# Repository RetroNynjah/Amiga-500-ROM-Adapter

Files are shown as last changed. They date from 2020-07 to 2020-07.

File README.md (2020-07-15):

# Amiga 500 ROM Adapter
Adapter board that allows use of regular EPROMS on Amiga 500 Rev 5 boards
A500 boards with revision 6 and higher don't have these problems and don't need this adapter.

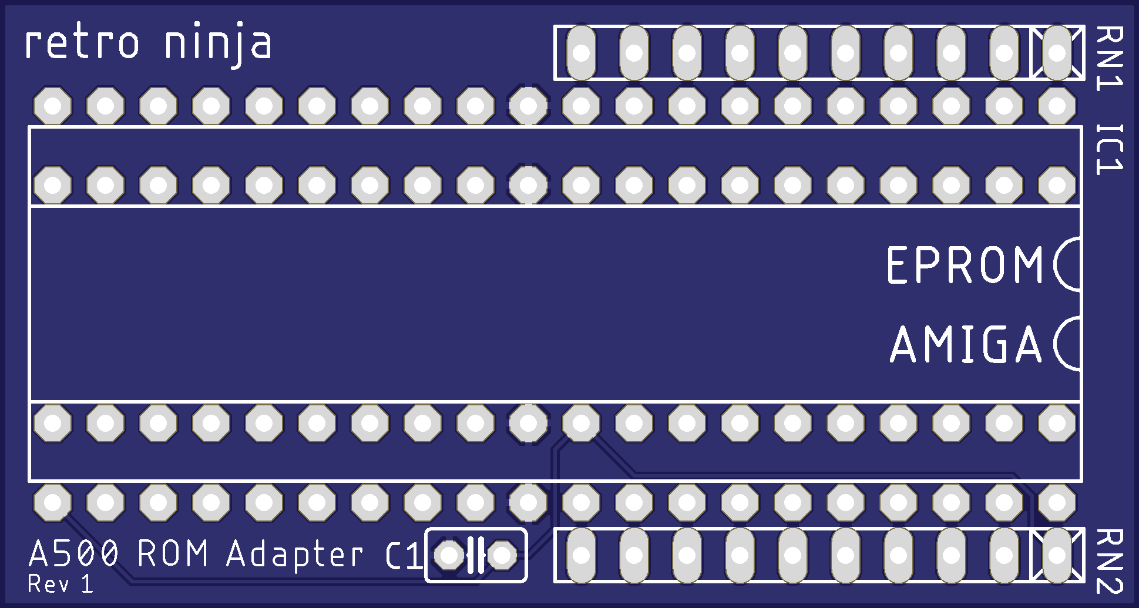
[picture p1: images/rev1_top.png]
PCB top
<br/>

To be able to use regular 27C400 or 27C800 EPROMS on Amiga 500 Rev 5 boards, you will need to lift out pin 31 on the chip, connecting it to VCC and instead connect pin 31 in the socket to pin 1 on the chip.
If that wasn't enough there are compatibility problems between some EPROMS and some machines/CPUs which requires pull-up resistors on the address pins.
This simple adapter board solves both problems. It re-routes the EPROM pins and has place for two optional resistor nets.

<br/>
*Diag ROM installed on a Rev 5 board*

## BOM
 |Component|Pcs |Name|Comment|
 |:--------|---:|:---|:------|
 | 100nF  ceramic capacitor| 1 | C1 | |
 | 4.7k resistor array | 1 | RN1, RN2 | 9 resistor arry (10SIP). 10k is probably OK as well| 
 | DIL-40 socket | 1 || EPROM socket for top side| 
 | 20-pin header | 2 || Round machined pin headers for bottom side (mates with motherboard) | 

Retro Ninja

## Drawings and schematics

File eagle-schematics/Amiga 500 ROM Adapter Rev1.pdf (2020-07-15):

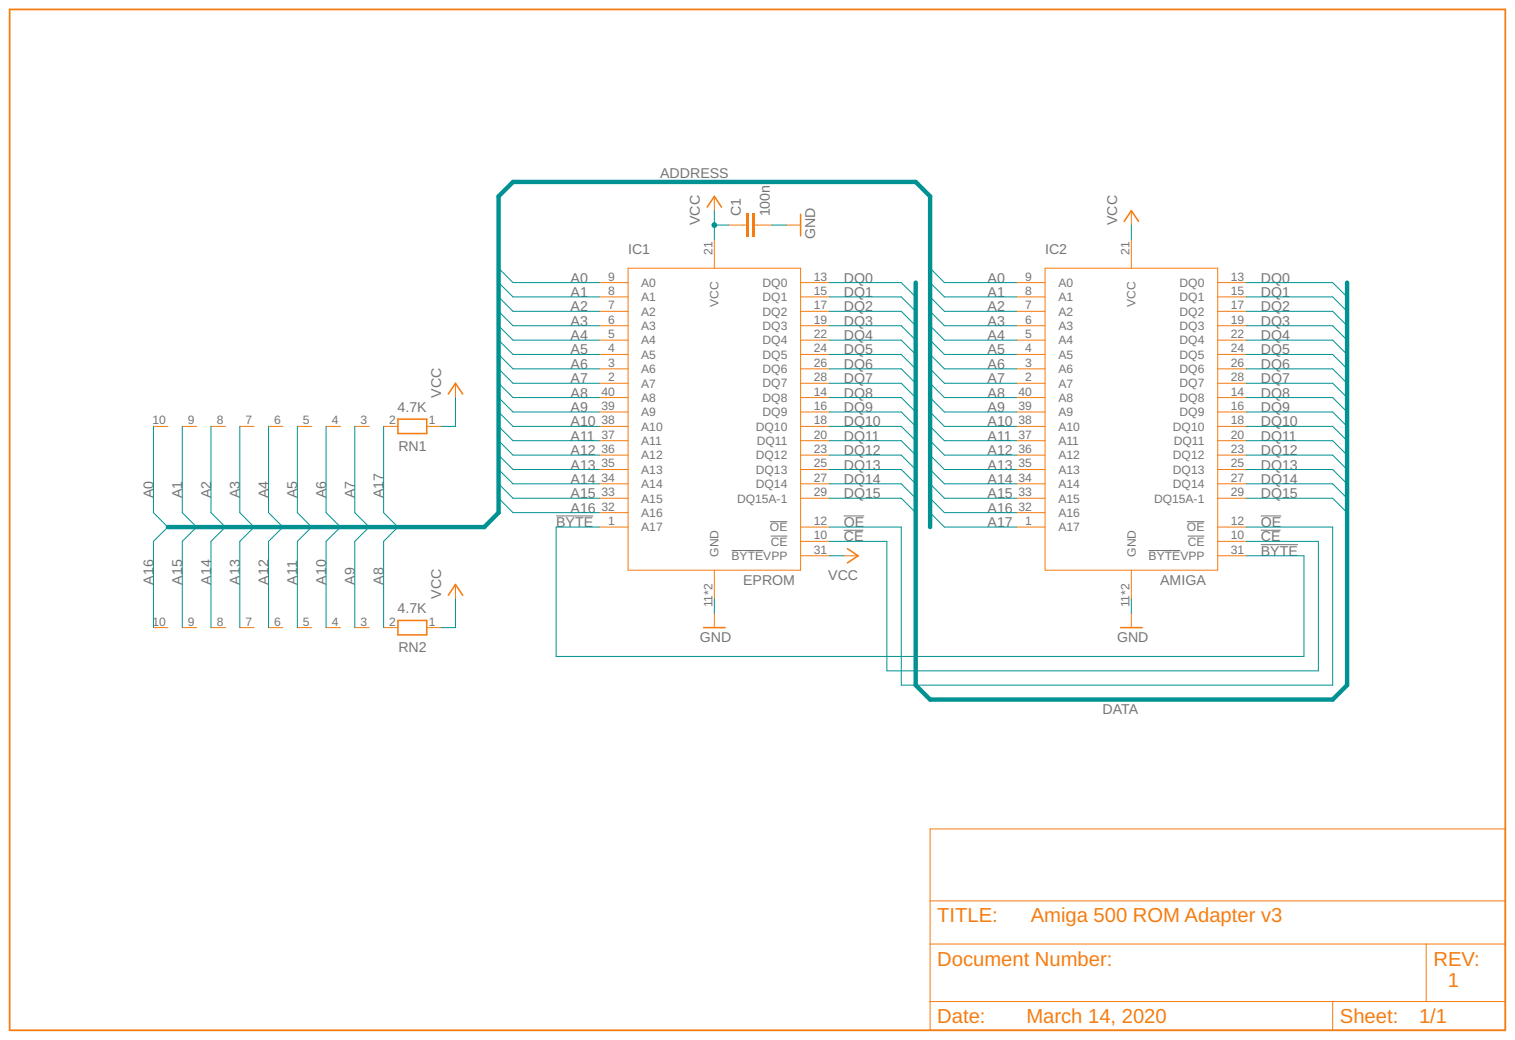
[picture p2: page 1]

Document Number: | REV: 1

Date: March 14, 2020 | Sheet: 1/1

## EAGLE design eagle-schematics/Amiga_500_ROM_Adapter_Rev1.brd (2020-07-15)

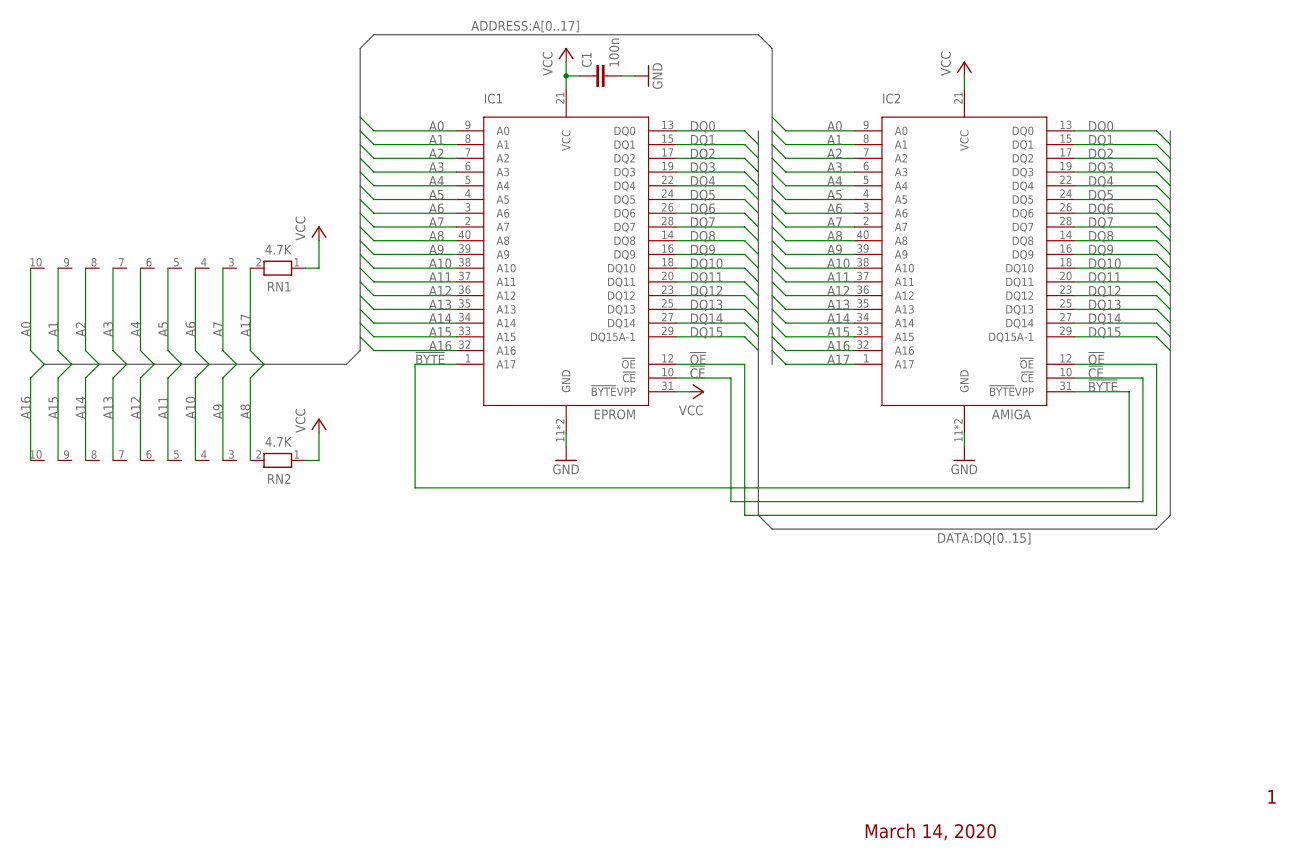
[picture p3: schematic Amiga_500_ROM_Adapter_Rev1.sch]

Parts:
C1: 100n; C025-025X050
IC1: EPROM; DIL40-6
IC2: AMIGA; DIL40-6
RN1, RN2: 4.7K; RN-10

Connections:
!BYTE: IC1.1 (A17), IC2.31 (!BYTE!VPP)
!CE: IC1.10 (!CE), IC2.10 (!CE)
!OE: IC1.12 (!OE), IC2.12 (!OE)
A0: IC1.9 (A0), IC2.9 (A0), RN1.10
A1: IC1.8 (A1), IC2.8 (A1), RN1.9
A2: IC1.7 (A2), IC2.7 (A2), RN1.8
A3: IC1.6 (A3), IC2.6 (A3), RN1.7
A4: IC1.5 (A4), IC2.5 (A4), RN1.6
A5: IC1.4 (A5), IC2.4 (A5), RN1.5
A6: IC1.3 (A6), IC2.3 (A6), RN1.4
A7: IC1.2 (A7), IC2.2 (A7), RN1.3
A8: IC1.40 (A8), IC2.40 (A8), RN2.2
A9: IC1.39 (A9), IC2.39 (A9), RN2.3
A10: IC1.38 (A10), IC2.38 (A10), RN2.4
A11: IC1.37 (A11), IC2.37 (A11), RN2.5
A12: IC1.36 (A12), IC2.36 (A12), RN2.6
A13: IC1.35 (A13), IC2.35 (A13), RN2.7
A14: IC1.34 (A14), IC2.34 (A14), RN2.8
A15: IC1.33 (A15), IC2.33 (A15), RN2.9
A16: IC1.32 (A16), IC2.32 (A16), RN2.10
A17: IC2.1 (A17), RN1.2
DQ0: IC1.13 (DQ0), IC2.13 (DQ0)
DQ1: IC1.15 (DQ1), IC2.15 (DQ1)
DQ2: IC1.17 (DQ2), IC2.17 (DQ2)
DQ3: IC1.19 (DQ3), IC2.19 (DQ3)
DQ4: IC1.22 (DQ4), IC2.22 (DQ4)
DQ5: IC1.24 (DQ5), IC2.24 (DQ5)
DQ6: IC1.26 (DQ6), IC2.26 (DQ6)
DQ7: IC1.28 (DQ7), IC2.28 (DQ7)
DQ8: IC1.14 (DQ8), IC2.14 (DQ8)
DQ9: IC1.16 (DQ9), IC2.16 (DQ9)
DQ10: IC1.18 (DQ10), IC2.18 (DQ10)
DQ11: IC1.20 (DQ11), IC2.20 (DQ11)
DQ12: IC1.23 (DQ12), IC2.23 (DQ12)
DQ13: IC1.25 (DQ13), IC2.25 (DQ13)
DQ14: IC1.27 (DQ14), IC2.27 (DQ14)
DQ15: IC1.29 (DQ15A-1), IC2.29 (DQ15A-1)
GND: C1.2, IC1.11 (GND), IC1.30 (GND), IC2.11 (GND), IC2.30 (GND)
VCC: C1.1, IC1.21 (VCC), IC1.31 (!BYTE!VPP), IC2.21 (VCC), RN1.1, RN2.1

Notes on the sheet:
March 14, 2020

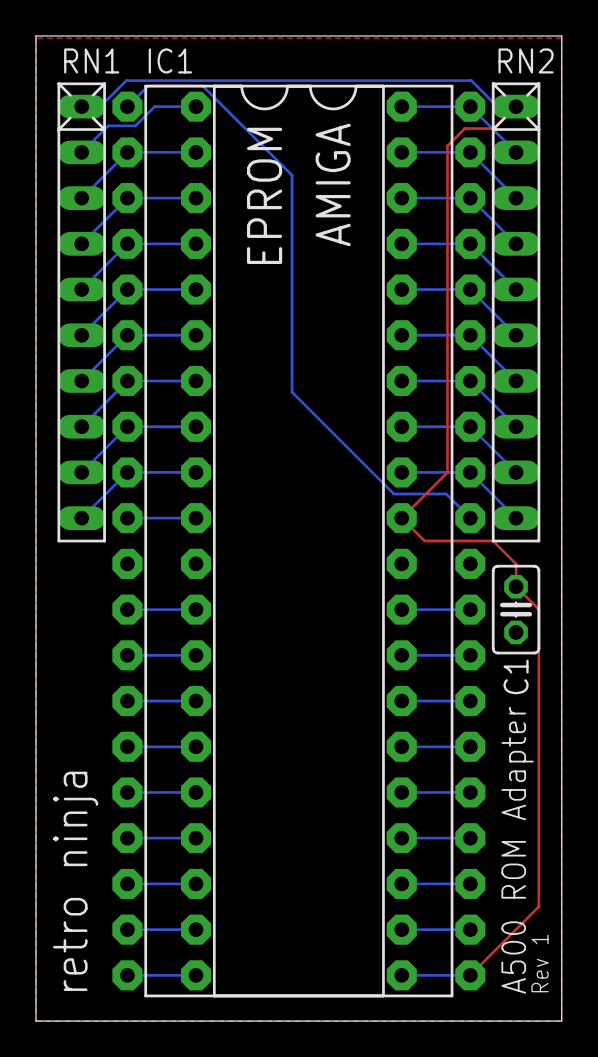
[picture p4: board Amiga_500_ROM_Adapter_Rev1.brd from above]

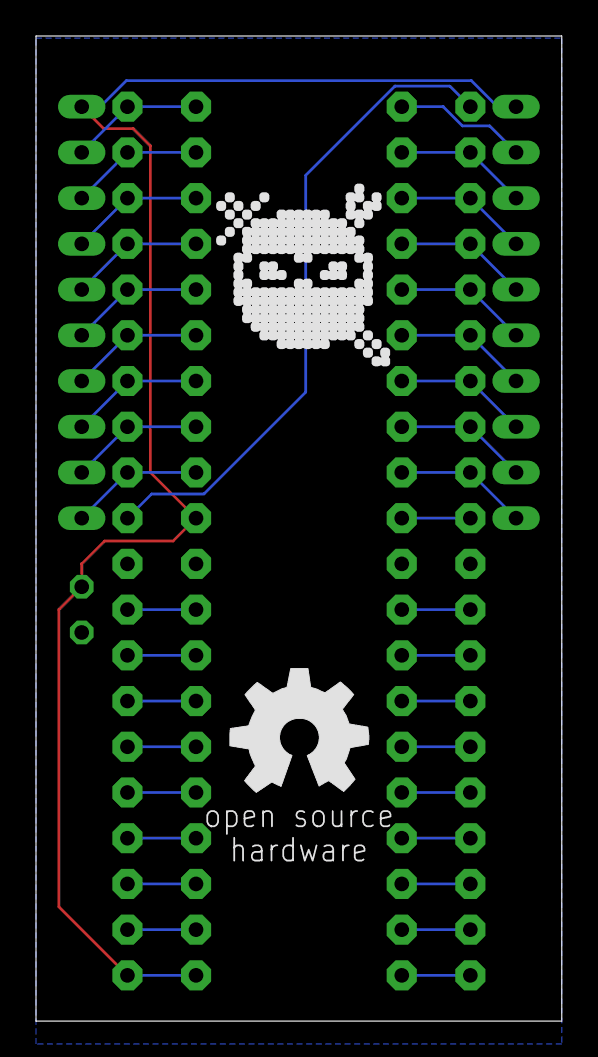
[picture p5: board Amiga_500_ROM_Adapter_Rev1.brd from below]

Board: 2 copper layers, 29.2 x 54.7 mm, 7 parts (2 on the bottom side), 39 nets.

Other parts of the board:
E$1: OSHW_8MM
U$1: RETRONINJA_NOTEXT_10MM
